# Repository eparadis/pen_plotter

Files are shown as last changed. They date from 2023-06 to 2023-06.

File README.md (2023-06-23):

# pen plotter in openSCAD

This is a "T" style differential drive XY gantry, similar in concept to the coreXY layout.

## WIP render of model
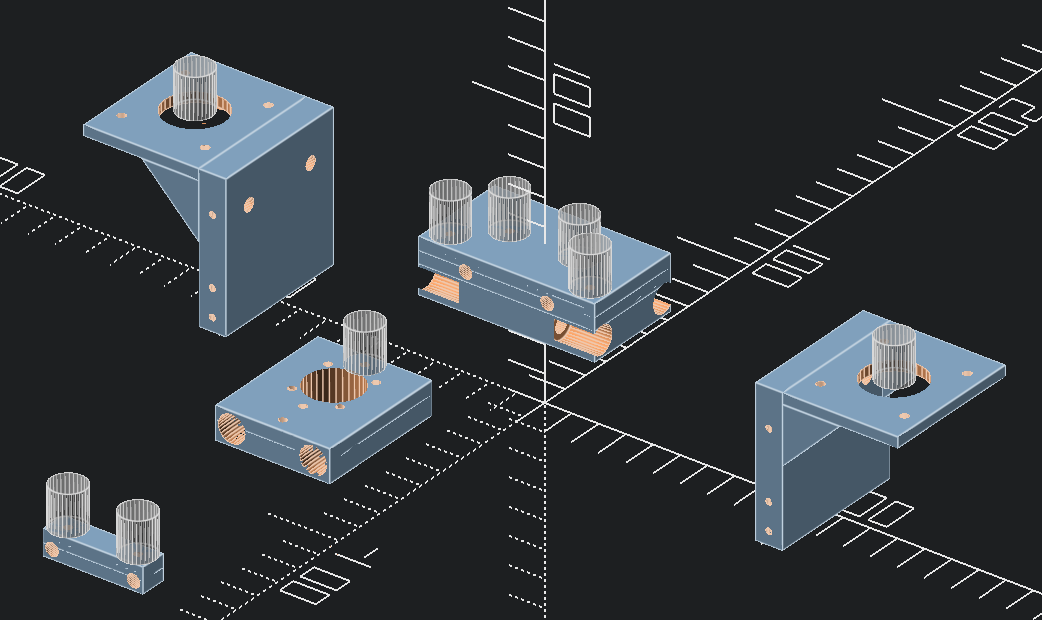
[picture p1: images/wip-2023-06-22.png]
work-in-progres render of the openSCAD model


# TODO
- The side stands need feet or outriggers to counter-balance the weight of the Y axis.
- The pulley locations are *approximate* and *need* to be finalized. (This may result in some other geometry changes as their mounting holes interfere with the linear bearings or axis rods.)
- The pen lift mechanism has not been designed. The Y axis carriage is designed to accept different pen lift mechanisms as I suspect these will vary depending on the actual pen used.
- The maximum extents of the pen plotter should be calculated in openSCAD and reported to the user on render to ensure paremter changes result in a useful print area.
- There is no wiring diagram yet, although this will be relatively trivial. The stepper motors are driven by EasyDrivers or similar connected to an Arduino or Raspberry Pi.
- There is no software configuration yet. There are several existing, well-documented differential drive pen plotter projects to take inspiration from.

# Parts required
- four 5mm diameter ~200mm long stainless steel rods
- eight LM5UU linear bearings
- toothed belt - I am using 2mm pitch, 6mm wide GT2, but all pulleys are printed and therefore you can print to match whatever timing belt you have on-hand
- two NEMA-17 stepper motors
- electronics to drive and control the stepper motors
  - BigEasy drivers, etc
  - Arduino, Raspberry Pi, etc
- power supply

# Customizing
The `scad/common.scad` file contains the highest level parameters for the plotter. You should be able to modify parameters there to adjust to the parts you have on-hand and your own 3D printer tolerances. For example, you could redefine the diameter of the stainless steel rods or use different linear bearings.

# Images
## Early sketch of the printer layout
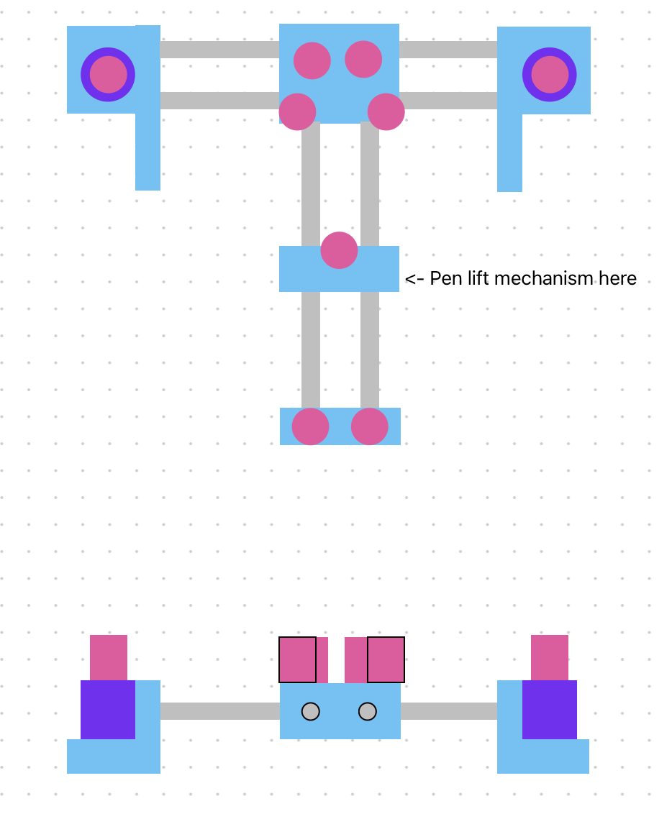
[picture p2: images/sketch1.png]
Early sketch


## Sketch of the belt path
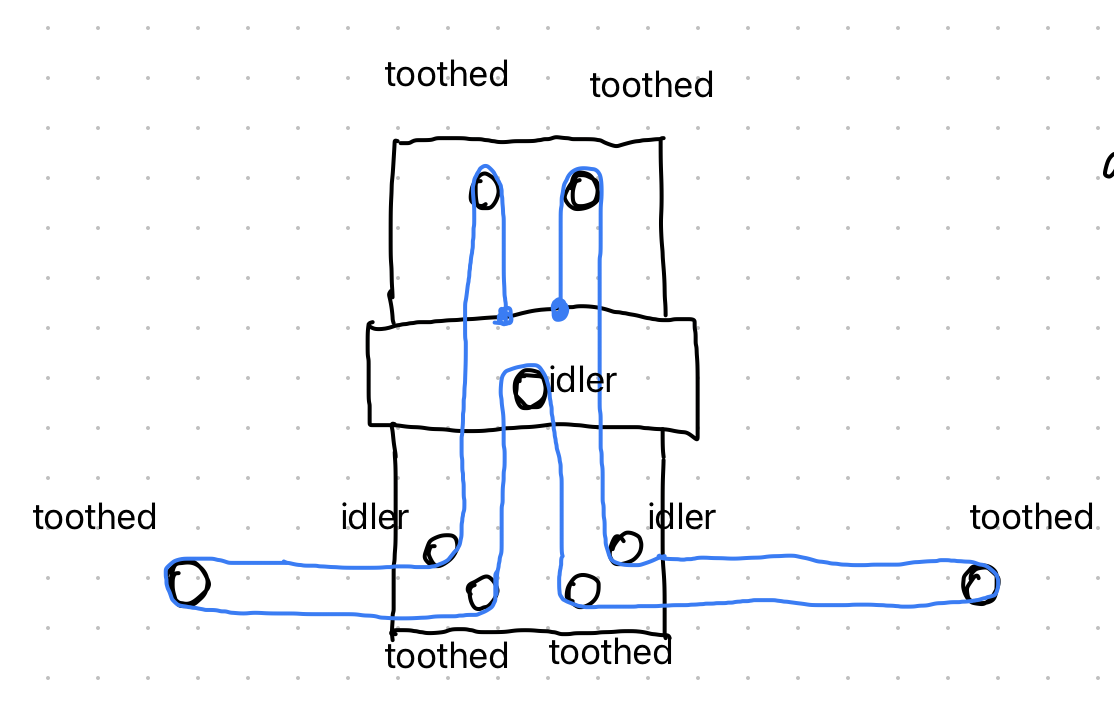
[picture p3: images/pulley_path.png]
Sketch of belt path


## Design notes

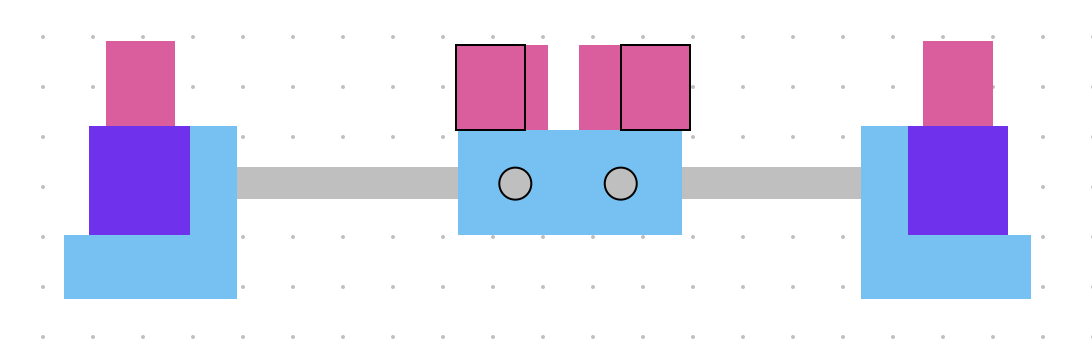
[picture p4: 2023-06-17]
images/sketch2.png

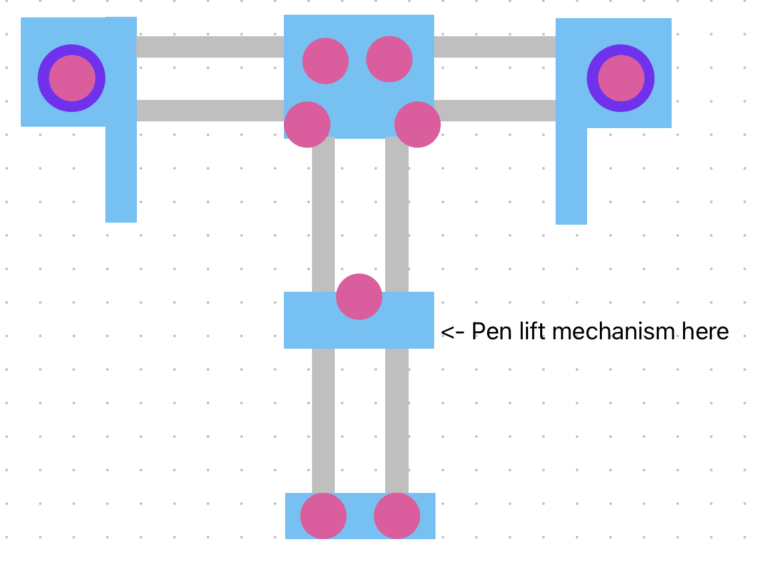
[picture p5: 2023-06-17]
images/sketch3.png

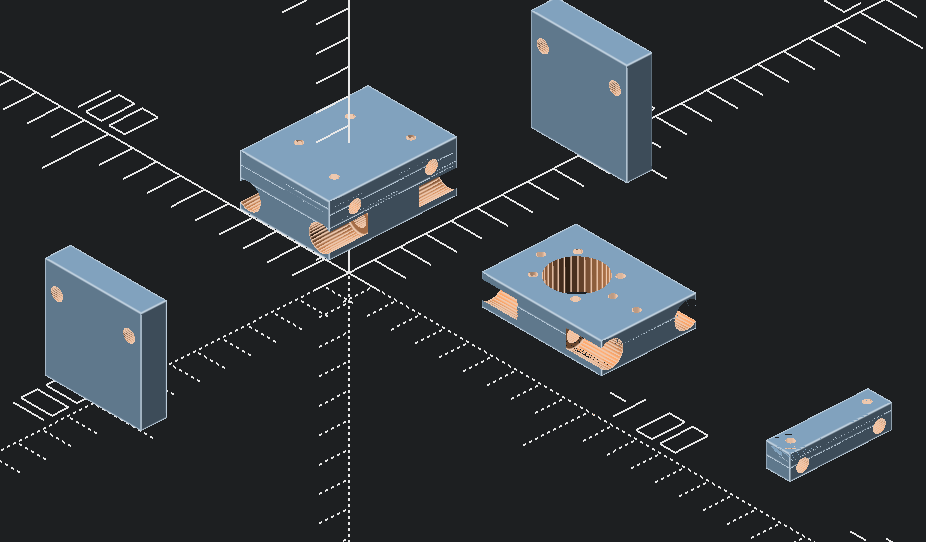
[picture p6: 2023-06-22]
images/wip-2023-06-21.png

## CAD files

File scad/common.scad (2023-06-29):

eps = 0.01;
$fn= $preview ? 32 : 128;

x_carriage_width = 65;
y_carriage_depth = 50;

x_rod_spacing = 30;
x_rod_height = 40;
y_rod_spacing = 30;
y_rod_height = 48;

lin_bearing_OD_measured = 9.97;
lin_bearing_OD = lin_bearing_OD_measured + 0.2; // needs more clearance when 3D printing in XY plane
lin_bearing_length = 14.95;

rod_OD = 4.98;
rod_clr = 1;
rod_pressfit_horiz = 5.0; // a bit tight, but a little filing makes a good snug fit
x_rod_length = 215;
y_rod_length = 215;

M3_self_thread = 3.0; // for vertical (along 3D printer Z axis) holes only.
M3_pass_through = 3.2; // for vertical holes only
M3_self_thread_horiz = 2.6; // for horizontal (along 3D printer XY plane) holes only.
M3_pass_through_horiz = 3.0; // for horizontal holes only

pulley_deck_height = 54;

pen_lifter_bolt_pattern_diameter = 25;

// LIN Engineering stepper 4118M-39D-01
stepper_bolt_pattern_diameter = 43.51;
stepper_axle_diameter = 4.98;
stepper_axle_length = 22;
stepper_body_width = 42.5;
stepper_body_depth = 42.5;
stepper_body_height = 39.6;
stepper_boss_diameter = 22;
stepper_boss_height = 2;
stepper_rear_axle_length = 8.5;

pulley_diameter = 11.81; // the effective diameter of the pulley. from highest points on teeth across (from a printed 20T pulley)
belt_thickness = 1.06; // the thickness of the belt, not including the teeth
// the belt wrapped around the pulley is 14.17mm in diameter
// larger than the 13.93 you'd expect from belt_thickness * 2 + pulley_diameter

inner_idler_spacing = 2*(pulley_diameter + belt_thickness); // the distance between the two inner idlers on the x carriage
outer_idler_spacing = 4*(pulley_diameter + belt_thickness); // the distance between the two outer idlers on the x carriage
outer_idler_offset = pulley_diameter; // how far forward the outer idlers are offset from the center line of the x axis

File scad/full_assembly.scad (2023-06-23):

include <common.scad>
use <x_carriage.scad>
use <side_stand.scad>
use <y_axis_endcap.scad>
use <y_carriage.scad>
use <pulleys.scad>

translate([0, 0, x_rod_height])
  x_carriage();

translate([x_rod_length/2, 0, 0])
  side_stand();

translate([-x_rod_length/2, 0, 0])
  rotate([0, 0, 180])
    side_stand();

translate([0, -y_rod_length, y_rod_height])
  y_axis_endcap();

translate([0, -y_rod_length/2, y_rod_height])
  y_carriage();

%translate([0, 0, pulley_deck_height]) pulleys();

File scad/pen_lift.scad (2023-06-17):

// holds the pen and lifts it off the drawing surface

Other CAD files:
scad/pulleys.scad
scad/rod_clamps.scad
scad/side_stand.scad
scad/smooth_idler_pulley.scad
scad/x_carriage.scad
scad/y_axis_endcap.scad
scad/y_carriage.scad

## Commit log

2023-06-17 five subassemblies, six counting the mirrored stand
    [pen_lift.scad, side_stand.scad, x_carriage.scad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]
2023-06-21 simple x carriage
    [common.scad, x_carriage.scad]
2023-06-21 y axis rod clamp
    [common.scad, x_carriage.scad]
2023-06-22 mounting holes for the pulleys on the x carriage
    [common.scad, x_carriage.scad]
2023-06-22 beginnings of the side stands
    [common.scad, side_stand.scad]
2023-06-22 start to assemble the pieces relative to each other
    [full_assembly.scad, x_carriage.scad]
2023-06-22 y axis endcap; unify Z heights
    [common.scad, full_assembly.scad, x_carriage.scad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]
2023-06-22 start of the y axis carriage
    [common.scad, full_assembly.scad, y_carriage.scad]
2023-06-22 add pulley deck to y carriage
    [y_carriage.scad]
2023-06-22 add a way to mount the pen lifter to the y carriage
    [common.scad, y_carriage.scad]
2023-06-22 reduce y rod and pulley deck height - req'd several corrections to height calculations
    [common.scad, x_carriage.scad, y_axis_endcap.scad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]
2023-06-22 confirmed measurements
    [common.scad]
2023-06-22 horizontal press fit for rod seems ok
    [common.scad]
2023-06-22 motor measurements
    [common.scad]
2023-06-22 swapping to full coverage and a 0.1 increase was still too tight
    [common.scad, y_carriage.scad]
2023-06-22 add more material to outside wall
    [y_carriage.scad]
2023-06-22 linear bearing press fits tightly with +0.2
    [common.scad]
2023-06-22 rename variable to not lead with numeral
    [common.scad, x_carriage.scad, y_axis_endcap.scad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]
2023-06-23 add stepper motor mounts to side stand - needed to raise the x and y rode heights
    [common.scad, side_stand.scad]
2023-06-23 add set screws for rods and a place to add balance outriggers
    [common.scad, side_stand.scad]
2023-06-23 starting to figure out where the pulleys go
    [common.scad, full_assembly.scad, pulleys.scad]
2023-06-23 harmonize pulley locations with mounting points
    [common.scad, x_carriage.scad, y_axis_endcap.scad]
2023-06-23 update TODO - stepper motor mounts added
2023-06-23 belt and pulley measurements
    [common.scad]
2023-06-23 correct y endcap pulley spacing and width
    [pulleys.scad, y_axis_endcap.scad]
2023-06-23 reduce volume of side stand
    [side_stand.scad]
2023-06-24 fully enclose linear bearings on x carriage
    [x_carriage.scad]
2023-06-25 pulley library and some pulley configs
2023-06-26 smooth idler pulley
    [smooth_idler_pulley.scad]
2023-06-29 rod clamp - probably useful as a component on other parts - i'm just using it as a stopgap fix for now
    [common.scad, rod_clamps.scad]
